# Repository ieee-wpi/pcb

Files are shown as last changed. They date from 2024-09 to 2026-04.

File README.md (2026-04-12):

# Essentials of PCB Design

[][cc-by-sa]

Project-oriented PCB design course taught at WPI. The course is a evening lecture series where students learn to layout and route an embedded system. Students then receive their boards and assemble them. The class was created by [Daniel Gorbunov](https://github.com/dgorbunov) and [Hubert Liu](https://github.com/124274sashimi) in 2024 and has been run every year since through the [IEEE WPI Student Branch](https://ieee.wpi.edu), which helps fund the class. You can reach us at [gr-pcb@wpi.edu](mailto:gr-pcb@wpi.edu) if you have questions.

### Lectures
| #  | Lecture				 |
| -- |--- 				 |
| 01 | PCB Basics 		 |
| 02 | Project Design |
| 03 | Layout + Routing |
| 04 | Working with KiCad |

### Materials
| Folder 	  | Contents		 |
| -- 	  | --- 			 |
| `datasheets` | Datasheets for major parts  |
| `sample_board`  | Sample board design |
| `slides` | PDFs of slides	 	|
| `starter_board` | Starter template design | 
| `code` | Code examples	 |

### Lecture Recordings

> Note: To access the lecture recordings, you must sign in with a WPI account. This is WPI's policy for Echo360 recordings.

| Year  | Term  | Echo360 |
| ----- | ----- | --- |
| 2024 | A-Term | [Link](https://echo360.org/collection/4c2d5caf-a301-4c32-a2dd-bdd8c8c0b9d9/public) | 
| 2025 | A-Term | [Link](https://echo360.org/collection/bc2acf2f-69f2-4496-9638-cb1b12c30087/public) |
| 2026 | C-Term | [Link](https://echo360.org/collection/0ecf9c61-5003-4061-9b4f-ee87c14e6741/public) |

## Getting Started
Not sure where to get started on your design? You'll need to download and install [KiCad](https://www.kicad.org/download/). You'll also need the [Arduino IDE](https://www.arduino.cc/en/software) to program your board.

### Board
To get started on your own board design, navigate to [starter_board](https://github.com/IEEE-WPI/pcb/tree/main/starter_board) and read the instructions in the `README` file.

### Code
To get started uploading code to your board, navigate to [code](https://github.com/IEEE-WPI/pcb/tree/main/code) and read the instructions in the `README` file.

## License
This work is licensed under a
[Creative Commons Attribution-ShareAlike 4.0 International License][cc-by-sa].

[][cc-by-sa]

[cc-by-sa]: http://creativecommons.org/licenses/by-sa/4.0/
[cc-by-sa-image]: https://licensebuttons.net/l/by-sa/4.0/88x31.png
[cc-by-sa-shield]: https://img.shields.io/badge/License-CC%20BY--SA%204.0-lightgrey.svg

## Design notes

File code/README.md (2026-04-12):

## Code Examples
This folder contains several code examples for the Track 1 board.

### Instructions
In order to program your board, you'll have to first flash a bootloader to your board (this will be done in class for you). Then, you can connect a USB cable to your board, compile, and upload one of the `.ino` files in this folder using the Arduino IDE. You can change and reupload the Arduino code at any time after the bootloader is flashed! 

Before you compile and upload code to your board:
1. Install the FastLED library in the Arduino IDE. Go to `Tools -> Manage Libraries`, and search for `FastLED`.
2. Modify any `#define` statements in the code to match any differences in your board. For example, if your board has a different number of LEDs, make sure to update the code to reflect that.
3. In the top left of the IDE, change your board to `Arduino Leonardo` and port to the USB port your board is connected to.
    - On Windows, the port looks like `COMX` where `X` is the port number. You can use Device Manager to find the port the board is connected to.
    - On macOS, the port looks like `/dev/cu.*`. You can run `ls /dev/cu*` in a shell to find the port the board is connected to.
    
You're encouraged to modify and write custom code for your board! You can look at FastLED's examples for inspiration.

### Demo
The `demo` folder contains a program that utilizes the onboard button to cycle through several different animations. You'll need to install the `Bounce2` debouncing library to compile this program.

### Rainbow
The `rainbow` folder contains a program that will iterate back and forth across the LEDs, changing their hue. This is based on FastLED's "cylon" example code.

### Flashlight
The `flashlight` folder contains a program that will turn all the LEDs on your board to white at their full brightness. Be careful, this is very bright and will use a lot of current!

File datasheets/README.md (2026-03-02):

## Datasheets
This folder contains datasheets for the major parts on the Track 1 board. A full list of exact parts used can be found in `digikey_bom.csv`.

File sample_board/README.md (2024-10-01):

## Sample Board
This folder contains the sample board for the Track 1 design. We've ordered these boards to help demonstrate what the Track 1 boards will do. 

**If you're in Track 1, we encourage you not to look at the sample board files, but rather come up with your own layout and routing solutions**. The sample board by no means represents "the best" design for the board.

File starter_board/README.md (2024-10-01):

## Starter Board

This folder contains the Track 1 starter board files. You'll want to open up the `.kicad_pro` file in KiCad. This is the root project file that will allow you to navigate between your board and schematic views.

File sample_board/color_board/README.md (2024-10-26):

### Color Board
This is a version of the sample board with full color silkscreen on both sides. JLCPCB offers this kind of silkscreen technology, but the Gerbers can only be made with their EDA software EasyEDA. The corresponding `.eprj` EasyEDA project file with the colorful silkscreen can only be opened with *EasyEDA Pro*.

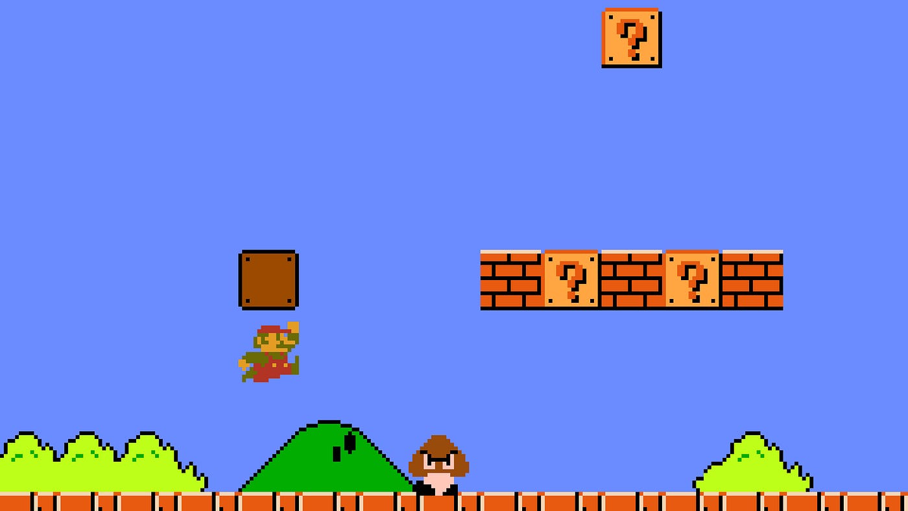
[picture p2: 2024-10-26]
sample_board/color_board/mario.jpg

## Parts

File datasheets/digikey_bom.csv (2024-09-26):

Country of Origin may be different at time of shipment.
Index | Manufacturer Part Number | Manufacturer Name | Description | Availability | Stock Status | Requested Quantity 1 | Pack Quantity 1 | Pack Type 1 | Digi-Key Part Number 1 | Unit Price 1 | Extended Price 1 | Minimum Order Quantity 1 | Requested Part Number | Lead Weeks | Datasheet | US Import Tariff | Note | Part Status | RoHS Status | Moisture Sensitivity Level (MSL) | ECCN | HTSUS | Country of Origin | Environmental Information | Original Part numbers
1 | ATMEGA32U4-AU | Microchip Technology | IC MCU 8BIT 32KB FLASH 44TQFP | 14,657 | In Stock | 1 | 1 | Tray | ATMEGA32U4-AU-ND | 5.29000 | $5.29 | 1 | atmega32u4-au | 4 | http://ww1.microchip.com/downloads/en/DeviceDoc/Atmel-7766-8-bit-AVR-ATmega16U4-32U4_Summary.pdf | - |  | Active | ROHS3 Compliant | 3 (168 Hours) | EAR99 | 8542.31.0015 | Thailand | https://ww1.microchip.com/downloads/aemDocuments/documents/corporate-responsibilty/environmental/product-regulatory-information/Semiconductor_EnvCoC.pdf|https://ww1.microchip.com/downloads/aemDocuments/documents/corporate-responsibilty/environmental/product-regulatory-information/Microchip_REACH_Statement.pdf | atmega32u4-au
2 | 865080142007 | Würth Elektronik | CAP ALUM 100UF 20% 6.3V SMD | 2,805 | In Stock | 1 | 1 | Cut Tape (CT) | 732-8472-1-ND | 0.20000 | $0.20 | 1 | 732-8472-1-ND | 26 | https://www.we-online.com/components/products/datasheet/865080142007.pdf | May apply on shipments to the U.S. |  | Active | ROHS3 Compliant | 1 (Unlimited) | EAR99 | 8532.22.0020 | China | https://mm.digikey.com/Volume0/opasdata/d220001/medias/docus/744/Certificate_of_Compliance_ROHS.pdf | 732-8472-1-ND
3 | CL21B105KPFNNNE | Samsung Electro-Mechanics | CAP CER 1UF 10V X7R 0805 | 763,033 | In Stock | 2 | 2 | Cut Tape (CT) | 1276-1275-1-ND | 0.10000 | $0.20 | 1 | 1276-1275-1-ND | 22 | http://www.samsungsem.com/kr/support/product-search/mlcc/CL21B105KPFNNNE.jsp | - |  | Active | ROHS3 Compliant | 1 (Unlimited) | EAR99 | 8532.24.0020 | Philippines | https://www.samsungsem.com/files/fileDown.do?key=ed1dfdfa-645e-4252-b707-17f9b1502dd1|https://www.samsungsem.com/global/support/certificate/product-stewardship.do | 1276-1275-1-ND
4 | CL21C220JBANFNC | Samsung Electro-Mechanics | CAP CER 22PF 50V C0G/NP0 0805 | 150,218 | In Stock | 2 | 2 | Cut Tape (CT) | 1276-2606-1-ND | 0.10000 | $0.20 | 1 | 1276-2606-1-ND | 22 | http://www.samsungsem.com/kr/support/product-search/mlcc/CL21C220JBANFNC.jsp | - |  | Active | ROHS3 Compliant | 1 (Unlimited) | EAR99 | 8532.24.0020 | China | https://www.samsungsem.com/files/fileDown.do?key=ed1dfdfa-645e-4252-b707-17f9b1502dd1|https://www.samsungsem.com/global/support/certificate/product-stewardship.do | 1276-2606-1-ND
5 | CL21B104KBCNNNC | Samsung Electro-Mechanics | CAP CER 0.1UF 50V X7R 0805 | 1,739,088 | In Stock | 1 | 1 | Cut Tape (CT) | 1276-1003-1-ND | 0.10000 | $0.10 | 1 | 1276-1003-1-ND | 22 | https://mm.digikey.com/Volume0/opasdata/d220001/medias/docus/609/CL21B104KBCNNN_Spec.pdf | - |  | Active | ROHS3 Compliant | 1 (Unlimited) | EAR99 | 8532.24.0020 | Philippines | https://www.samsungsem.com/files/fileDown.do?key=ed1dfdfa-645e-4252-b707-17f9b1502dd1|https://www.samsungsem.com/global/support/certificate/product-stewardship.do | 1276-1003-1-ND
6 | USB3076-30-A | GCT | MICRO B SKT, BOTTOM-SMT, R/A, 30 | 45,985 | In Stock | 1 | 1 | Cut Tape (CT) | 2073-USB3076-30-ACT-ND | 0.70000 | $0.70 | 1 | 2073-USB3076-30-ACT-ND | 9 | https://gct.co/files/specs/usb3076-spec.pdf | May apply on shipments to the U.S. |  | Active | ROHS3 Compliant | Not Applicable | EAR99 | 8536.69.4040 | China | https://gct.co/files/info/gct_certificate_of_compliance.pdf | 2073-USB3076-30-ACT-ND
7 | LNCD1-16M | NDK America, Inc. | CRYSTAL 16.0000MHZ 8PF SMD | 31,951 | In Stock | 1 | 1 | Cut Tape (CT) | 644-LNCD1-16MCT-ND | 0.58000 | $0.58 | 1 | 644-LNCD1-16MCT-ND | 15 | https://mm.digikey.com/Volume0/opasdata/d220001/medias/docus/973/NX5032GA.pdf | - |  | Active | RoHS Compliant | 1 (Unlimited) | EAR99 | 8541.60.0050 | China |  | 644-LNCD1-16MCT-ND
8 | B1701TW--20P000314U1930 | Harvatek Corporation | LED WHITE 0805 SMD | 31,804 | In Stock | 2 | 2 | Cut Tape (CT) | 3147-B1701TW--20P000314U1930CT-ND | 0.10000 | $0.20 | 1 | 3147-B1701TW--20P000314U1930CT-ND | 8 | https://mm.digikey.com/Volume0/opasdata/d220001/medias/docus/3791/B1701TW--20P000314U1930.pdf | - |  | Active | RoHS Compliant | 2A (4 Weeks) | EAR99 | 8541.41.0000 | Taiwan | https://mm.digikey.com/Volume0/opasdata/d220001/medias/docus/6223/Harvatek%20Corp%20REACH%20235%20Jun%202023%20Statement.pdf | 3147-B1701TW--20P000314U1930CT-ND
9 | PH1-20-UA | Adam Tech | CONN HEADER VERT 20POS 2.54MM | 8,135 | In Stock | 1 | 1 | Bag | 2057-PH1-20-UA-ND | 0.36000 | $0.36 | 1 | 2057-PH1-20-UA-ND | 14 | https://app.adam-tech.com/products/download/data_sheet/201605/ph1-xx-ua-data-sheet.pdf | May apply on shipments to the U.S. |  | Active | ROHS3 Compliant | 1 (Unlimited) | EAR99 | 8536.69.4040 | China |  | 2057-PH1-20-UA-ND
10 | PH2-06-UA | Adam Tech | CONN HEADER VERT 6POS 2.54MM | 11,624 | In Stock | 1 | 1 | Bag | 2057-PH2-06-UA-ND | 0.12000 | $0.12 | 1 | 2057-PH2-06-UA-ND | 14 | https://app.adam-tech.com/products/download/data_sheet/202065/ph2-xx-ua-data-sheet.pdf | May apply on shipments to the U.S. |  | Active | ROHS3 Compliant | 1 (Unlimited) | EAR99 | 8536.69.4040 | China |  | 2057-PH2-06-UA-ND
11 | RC0805FR-07100RL | YAGEO | RES 100 OHM 1% 1/8W 0805 | 169,983 | In Stock | 2 | 2 | Cut Tape (CT) | 311-100CRCT-ND | 0.10000 | $0.20 | 1 | 311-100CRCT-ND | 18 | https://www.yageo.com/upload/media/product/products/datasheet/rchip/PYu-RC_Group_51_RoHS_L_12.pdf | May apply on shipments to the U.S. |  | Active | ROHS3 Compliant | 1 (Unlimited) | EAR99 | 8533.21.0030 | Taiwan | https://www.yageo.com/en/Download/Index/certificates#rchip | 311-100CRCT-ND
12 | RC0805FR-0722RL | YAGEO | RES 22 OHM 1% 1/8W 0805 | 499,387 | In Stock | 2 | 2 | Cut Tape (CT) | 311-22.0CRCT-ND | 0.10000 | $0.20 | 1 | 311-22.0CRCT-ND | 18 | https://www.yageo.com/upload/media/product/products/datasheet/rchip/PYu-RC_Group_51_RoHS_L_12.pdf | May apply on shipments to the U.S. |  | Active | ROHS3 Compliant | 1 (Unlimited) | EAR99 | 8533.21.0030 | Taiwan | https://www.yageo.com/en/Download/Index/certificates#rchip | 311-22.0CRCT-ND
13 | RC0805FR-071KL | YAGEO | RES 1K OHM 1% 1/8W 0805 | 1,825,316 | In Stock | 1 | 1 | Cut Tape (CT) | 311-1.00KCRCT-ND | 0.10000 | $0.10 | 1 | 311-1.00KCRCT-ND | 18 | https://www.yageo.com/upload/media/product/products/datasheet/rchip/PYu-RC_Group_51_RoHS_L_12.pdf | May apply on shipments to the U.S. |  | Active | ROHS3 Compliant | 1 (Unlimited) | EAR99 | 8533.21.0030 | Taiwan | https://www.yageo.com/en/Download/Index/certificates#rchip | 311-1.00KCRCT-ND
14 | RC0805FR-07470RL | YAGEO | RES 470 OHM 1% 1/8W 0805 | 415,773 | In Stock | 1 | 1 | Cut Tape (CT) | 311-470CRCT-ND | 0.10000 | $0.10 | 1 | 311-470CRCT-ND | 18 | https://www.yageo.com/upload/media/product/products/datasheet/rchip/PYu-RC_Group_51_RoHS_L_12.pdf | May apply on shipments to the U.S. |  | Active | ROHS3 Compliant | 1 (Unlimited) | EAR99 | 8533.21.0030 | Taiwan | https://www.yageo.com/en/Download/Index/certificates#rchip | 311-470CRCT-ND
15 | 2686 | Adafruit Industries LLC | ADDRESS LED DISC SERIAL RGB 10PK | 185 | In Stock | 1 | 1 | Bulk | 1528-1541-ND | 4.95000 | $4.95 | 1 | 1528-1541-ND | 6 | https://cdn-shop.adafruit.com/product-files/2686/SK6812MINI_REV.01-1-2.pdf | - |  | Active | ROHS3 Compliant | 5A (24 Hours) | EAR99 | 8541.41.0000 | China |  | 1528-1541-ND

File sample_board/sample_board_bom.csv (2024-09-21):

# | Reference | Qty | Value | Footprint | DNP
1 | C1 | 1 | 100uF | Capacitor_SMD:CP_Elec_5x5.3
2 | C2, C6 | 2 | 1uF | Capacitor_SMD:C_0805_2012Metric_Pad1.18x1.45mm_HandSolder
3 | C3, C4 | 2 | 22pF | Capacitor_SMD:C_0805_2012Metric_Pad1.18x1.45mm_HandSolder
4 | C5 | 1 | 0.1uF | Capacitor_SMD:C_0805_2012Metric_Pad1.18x1.45mm_HandSolder
5 | D1 | 1 | TX | LED_SMD:LED_0805_2012Metric_Pad1.15x1.40mm_HandSolder
6 | D2 | 1 | RX | LED_SMD:LED_0805_2012Metric_Pad1.15x1.40mm_HandSolder
7 | D3, D4, D5, D6, D7, D8, D9, D10, D11, D12, D13, D14, D15, D16, D17, D18, D19, D20, D21, D22, D23, D24, D25, D26, D27, D28, D29 | 27 | SK6812MINI | LED_SMD:LED_SK6812MINI_PLCC4_3.5x3.5mm_P1.75mm
8 | J1, J2 | 2 | Conn_01x10 | Connector_PinHeader_2.54mm:PinHeader_1x10_P2.54mm_Vertical
9 | J3 | 1 | ICSP | Connector_PinHeader_2.54mm:PinHeader_2x03_P2.54mm_Vertical
10 | J4 | 1 | USB_B_Micro | Connector_USB:USB_Micro-B_GCT_USB3076-30-A
11 | JP1 | 1 | Jumper_2_Open | Jumper:SolderJumper-2_P1.3mm_Open_TrianglePad1.0x1.5mm
12 | R1, R2 | 2 | 100 | Resistor_SMD:R_0805_2012Metric_Pad1.20x1.40mm_HandSolder
13 | R3, R4 | 2 | 22 | Resistor_SMD:R_0805_2012Metric_Pad1.20x1.40mm_HandSolder
14 | R5 | 1 | 10k | Resistor_SMD:R_0805_2012Metric_Pad1.20x1.40mm_HandSolder
15 | R6 | 1 | 470 | Resistor_SMD:R_0805_2012Metric_Pad1.20x1.40mm_HandSolder
16 | U1 | 1 | ATmega32U4-A | Package_QFP:TQFP-44_10x10mm_P0.8mm
17 | Y1 | 1 | 16MHz | Crystal:Crystal_SMD_5032-2Pin_5.0x3.2mm

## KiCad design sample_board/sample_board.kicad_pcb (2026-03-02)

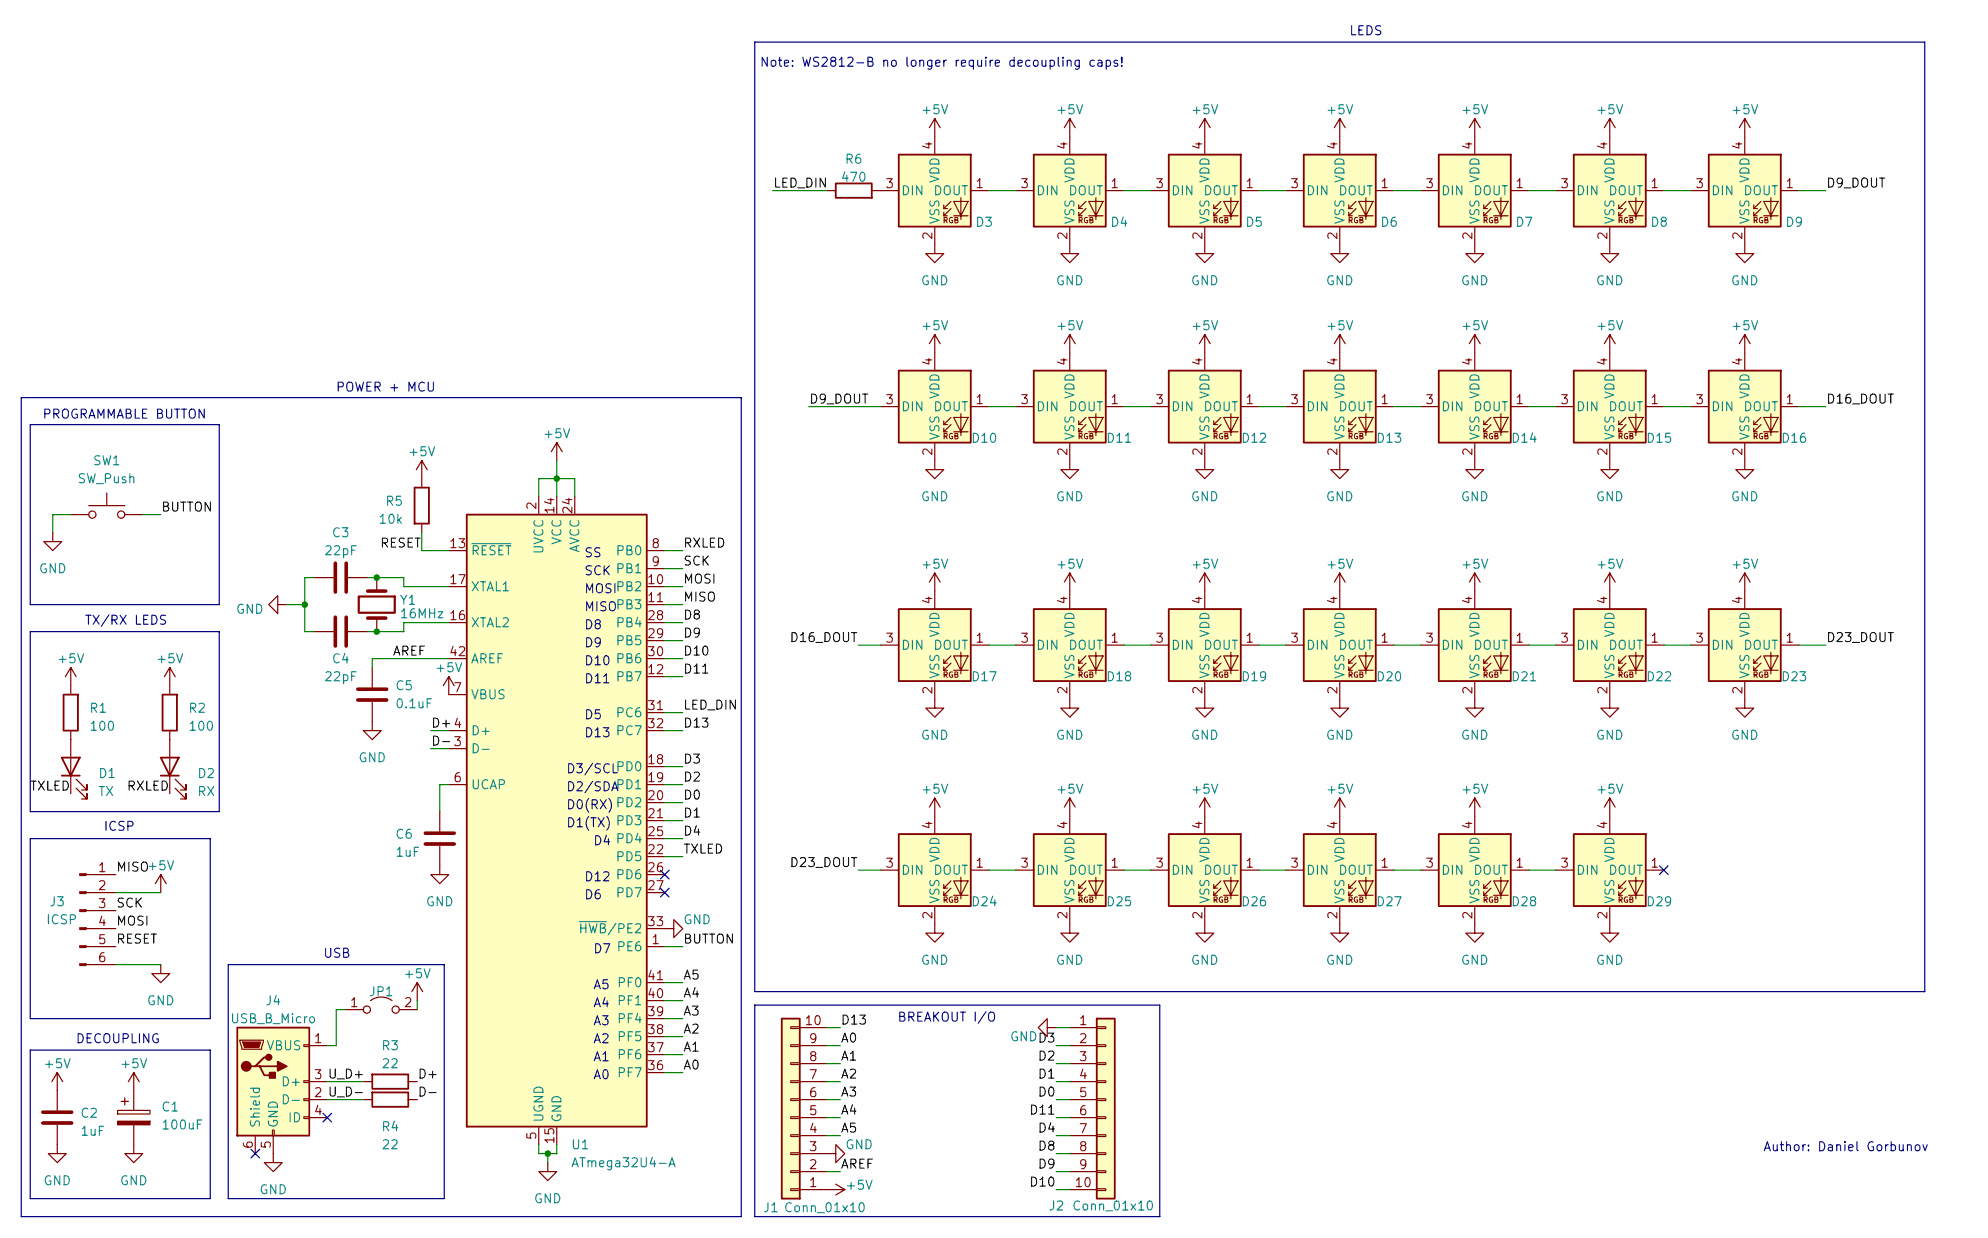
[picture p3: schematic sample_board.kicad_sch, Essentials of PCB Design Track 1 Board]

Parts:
C1: 100uF; CP_Elec_5x5.3
C2, C6: 1uF; C_0805_2012Metric_Pad1.18x1.45mm_HandSolder
C3, C4: 22pF; C_0805_2012Metric_Pad1.18x1.45mm_HandSolder
C5: 0.1uF; C_0805_2012Metric_Pad1.18x1.45mm_HandSolder
D1: TX; LED_0805_2012Metric_Pad1.15x1.40mm_HandSolder
D2: RX; LED_0805_2012Metric_Pad1.15x1.40mm_HandSolder
D3, D4, D5, D6, D7, D8, D9, D10, D11, D12, D13, D14, D15, D16, D17, D18, D19, D20, D21, D22, D23, D24, D25, D26, D27, D28, D29: SK6812MINI; LED_SK6812MINI_PLCC4_3.5x3.5mm_P1.75mm
J1, J2: Conn_01x10; PinHeader_1x10_P2.54mm_Vertical
J3: ICSP; PinHeader_2x03_P2.54mm_Vertical
J4: USB_B_Micro; USB_Micro-B_GCT_USB3076-30-A
JP1: Jumper_2_Open; SolderJumper-2_P1.3mm_Open_TrianglePad1.0x1.5mm
R1, R2: 100; R_0805_2012Metric_Pad1.20x1.40mm_HandSolder
R3, R4: 22; R_0805_2012Metric_Pad1.20x1.40mm_HandSolder
R5: 10k; R_0805_2012Metric_Pad1.20x1.40mm_HandSolder
R6: 470; R_0805_2012Metric_Pad1.20x1.40mm_HandSolder
SW1: SW_Push; SW_SPST_PTS647_Sx38
U1: ATmega32U4-A; TQFP-44_10x10mm_P0.8mm
Y1: 16MHz; Crystal_SMD_5032-2Pin_5.0x3.2mm

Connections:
+5V: C1.1, C2.1, D3.4 (VDD), D4.4 (VDD), D5.4 (VDD), D6.4 (VDD), D7.4 (VDD), D8.4 (VDD), D9.4 (VDD), D10.4 (VDD), D11.4 (VDD), D12.4 (VDD), D13.4 (VDD), D14.4 (VDD), D15.4 (VDD), D16.4 (VDD), D17.4 (VDD), D18.4 (VDD), D19.4 (VDD), D20.4 (VDD), D21.4 (VDD), D22.4 (VDD), D23.4 (VDD), D24.4 (VDD), D25.4 (VDD), D26.4 (VDD), D27.4 (VDD), D28.4 (VDD), D29.4 (VDD), J1.1, J3.2, JP1.2 (B), R1.2, R2.2, R5.1, U1.2 (UVCC), U1.7 (VBUS), U1.14 (VCC), U1.24 (AVCC), U1.34 (VCC), U1.44 (AVCC)
/A0: J1.9, U1.36 (PF7)
/A1: J1.8, U1.37 (PF6)
/A2: J1.7, U1.38 (PF5)
/A3: J1.6, U1.39 (PF4)
/A4: J1.5, U1.40 (PF1)
/A5: J1.4, U1.41 (PF0)
/AREF: C5.1, J1.2, U1.42 (AREF)
/BUTTON: SW1.2, U1.1 (PE6)
/D0: J2.5, U1.20 (PD2)
/D1: J2.4, U1.21 (PD3)
/D2: J2.3, U1.19 (PD1)
/D3: J2.2, U1.18 (PD0)
/D4: J2.7, U1.25 (PD4)
/D8: J2.8, U1.28 (PB4)
/D9: J2.9, U1.29 (PB5)
/D9_DOUT: D9.1 (DOUT), D10.3 (DIN)
/D10: J2.10, U1.30 (PB6)
/D11: J2.6, U1.12 (PB7)
/D13: J1.10, U1.32 (PC7)
/D16_DOUT: D16.1 (DOUT), D17.3 (DIN)
/D23_DOUT: D23.1 (DOUT), D24.3 (DIN)
/D+: R3.1, U1.4 (D+)
/D-: R4.1, U1.3 (D-)
/LED_DIN: R6.1, U1.31 (PC6)
/MISO: J3.1, U1.11 (PB3)
/MOSI: J3.4, U1.10 (PB2)
/RESET: J3.5, R5.2, U1.13 (~RESET)
/RXLED: D2.1 (K), U1.8 (PB0)
/SCK: J3.3, U1.9 (PB1)
/TXLED: D1.1 (K), U1.22 (PD5)
/U_D+: J4.3 (D+), R3.2
/U_D-: J4.2 (D-), R4.2
GND: C1.2, C2.2, C3.2, C4.2, C5.2, C6.2, D3.2 (VSS), D4.2 (VSS), D5.2 (VSS), D6.2 (VSS), D7.2 (VSS), D8.2 (VSS), D9.2 (VSS), D10.2 (VSS), D11.2 (VSS), D12.2 (VSS), D13.2 (VSS), D14.2 (VSS), D15.2 (VSS), D16.2 (VSS), D17.2 (VSS), D18.2 (VSS), D19.2 (VSS), D20.2 (VSS), D21.2 (VSS), D22.2 (VSS), D23.2 (VSS), D24.2 (VSS), D25.2 (VSS), D26.2 (VSS), D27.2 (VSS), D28.2 (VSS), D29.2 (VSS), J1.3, J2.1, J3.6, J4.5 (GND), SW1.1, U1.5 (UGND), U1.15 (GND), U1.23 (GND), U1.33 (~HWB/PE2), U1.35 (GND), U1.43 (GND)
unnamed: D1.2 (A), R1.1
unnamed: D2.2 (A), R2.1
unnamed: D3.3 (DIN), R6.2
unnamed: D3.1 (DOUT), D4.3 (DIN)
unnamed: D4.1 (DOUT), D5.3 (DIN)
unnamed: D5.1 (DOUT), D6.3 (DIN)
unnamed: D6.1 (DOUT), D7.3 (DIN)
unnamed: D7.1 (DOUT), D8.3 (DIN)
unnamed: D8.1 (DOUT), D9.3 (DIN)
unnamed: D10.1 (DOUT), D11.3 (DIN)
unnamed: D11.1 (DOUT), D12.3 (DIN)
unnamed: D12.1 (DOUT), D13.3 (DIN)
unnamed: D13.1 (DOUT), D14.3 (DIN)
unnamed: D14.1 (DOUT), D15.3 (DIN)
unnamed: D15.1 (DOUT), D16.3 (DIN)
unnamed: D17.1 (DOUT), D18.3 (DIN)
unnamed: D18.1 (DOUT), D19.3 (DIN)
unnamed: D19.1 (DOUT), D20.3 (DIN)
unnamed: D20.1 (DOUT), D21.3 (DIN)
unnamed: D21.1 (DOUT), D22.3 (DIN)
unnamed: D22.1 (DOUT), D23.3 (DIN)
unnamed: D24.1 (DOUT), D25.3 (DIN)
unnamed: D25.1 (DOUT), D26.3 (DIN)
unnamed: D26.1 (DOUT), D27.3 (DIN)
unnamed: D27.1 (DOUT), D28.3 (DIN)
unnamed: D28.1 (DOUT), D29.3 (DIN)
unnamed: J4.1 (VBUS), JP1.1 (A)
unnamed: C6.1, U1.6 (UCAP)
unnamed: C3.1, U1.17 (XTAL1), Y1.1
unnamed: C4.1, U1.16 (XTAL2), Y1.2

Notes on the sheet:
MOSI
D2/SDA
LEDS
D11
D3/SCL
USB
DECOUPLING
D1(TX)
D13
Note: WS2812-B no longer require decoupling caps!
Author: Daniel Gorbunov
PROGRAMMABLE BUTTON
MISO
D10
BREAKOUT I/O
POWER + MCU
TX/RX LEDS
ICSP
SCK
D12
D0(RX)

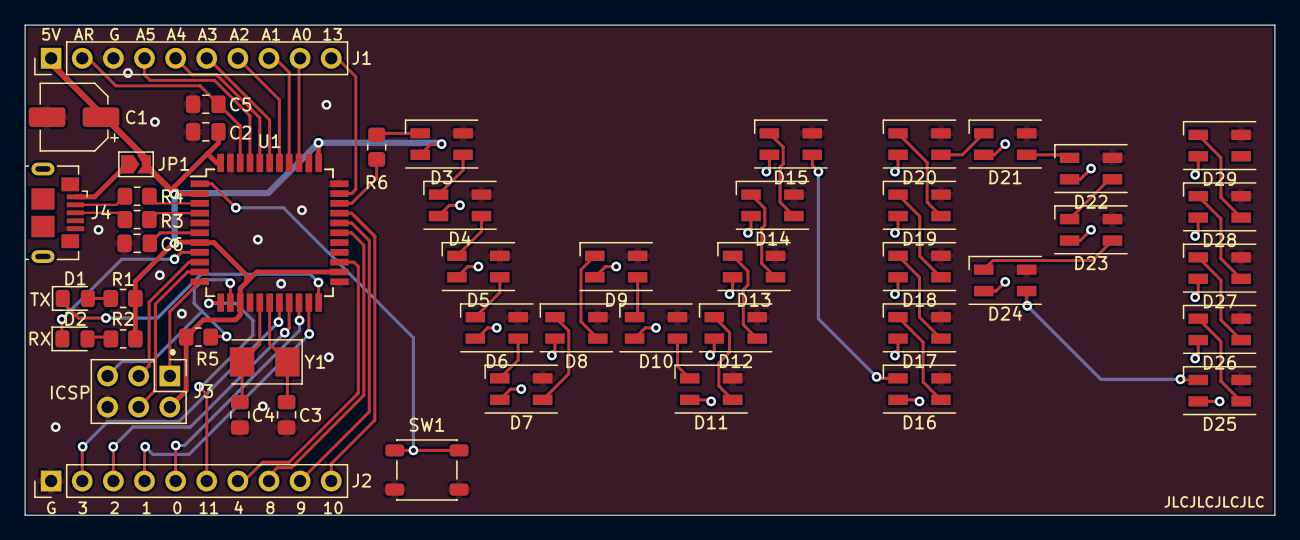
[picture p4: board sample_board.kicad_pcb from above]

Board: 2 copper layers, 102.0 x 40.0 mm, 49 parts (0 on the bottom side), 64 nets.

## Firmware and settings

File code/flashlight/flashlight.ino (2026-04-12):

/*
* Essentials of PCB Design
* Flashlight: Turns on all LEDs to white at full brightness
* This is very bright and will use a lot of current!
*
* Track 1 boards compile for Arduino Leonardo
* Requirements:
* - FastLED library
*/

#include <FastLED.h>

// Board-specific pins
#define NUM_LEDS 27
#define DATA_PIN 5

// Array of LEDs
CRGB leds[NUM_LEDS];

// Setup function - runs once at the start
void setup() { 
  FastLED.addLeds<NEOPIXEL, DATA_PIN>(leds, NUM_LEDS);
}

// Loop function - repeatedly called after setup()
void loop() {
  FastLED.showColor(CRGB(255, 255, 255), 255);
  FastLED.show();
}

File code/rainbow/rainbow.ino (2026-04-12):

/*
* Essentials of PCB Design
* Rainbow: Iterates back and forth across the LEDs, changing their hue.
* 
* Track 1 boards compile for Arduino Leonardo
* Requirements:
* - FastLED library
*/

#include <FastLED.h>

// Board-specific pins
#define NUM_LEDS 27
#define DATA_PIN 5

// Delay after each loop iteration (ms)
#define DELAY 50

// Brightness of all LEDs (0-255)
#define BRIGHTNESS 50

// Array of LEDs
CRGB leds[NUM_LEDS];

// Setup function - runs once at the start
void setup() { 
	FastLED.addLeds<WS2812,DATA_PIN,GRB>(leds,NUM_LEDS);
	FastLED.setBrightness(BRIGHTNESS);
}

// Loop function - repeatedly called after setup()
void loop() { 
	static uint8_t hue = 0;

	// Slide the leds in one direction
	for(int i = 0; i < NUM_LEDS; i++) {
    // Advance hue of current LED and write to LEDs
		leds[i] = CHSV(hue++, 255, 255);
		FastLED.show(); 

    // Fade all LEDs and wait
		fadeall();
		delay(DELAY);
	}

	// Slide the leds in the other direction
	for(int i = NUM_LEDS-1; i >= 0; i--) {
    // Advance hue of current LED and write to LEDs
		leds[i] = CHSV(hue++, 255, 255);
		FastLED.show();

    // Fade all LEDs and wait
		fadeall();
		delay(DELAY);
	}
}

// Scales the brightness of all LEDs
void fadeall() {
  for(int i = 0; i < NUM_LEDS; i++) { 
    leds[i].nscale8(200);
  }
}

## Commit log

2024-09-21 move repo to org
    [ieee_pcb_workshop-B_Cu.gbl, ieee_pcb_workshop-B_Mask.gbs, ieee_pcb_workshop-B_Paste.gbp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]
2024-09-24 cleanup stray gerber files
    [ieee_pcb_workshop-B_Cu.gbl, ieee_pcb_workshop-B_Mask.gbs, ieee_pcb_workshop-B_Paste.gbp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]
2024-09-25 reorg and update readme
    [ieee_pcb_workshop.csv, ieee_pcb_workshop.kicad_pcb, ieee_pcb_workshop.kicad_sch]
2024-09-26 untrack kicad cache files
    [ieee_pcb_workshop.csv, ieee_pcb_workshop.kicad_pcb, ieee_pcb_workshop.kicad_sch]
2024-09-26 add datasheets and new sample board files
    [digikey_bom.csv, sample_board.kicad_pcb, sample_board.kicad_sch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]
2024-09-26 remove cached starter board files
    [ieee_pcb_workshop.csv, starter_board.kicad_pcb, starter_board.kicad_sch]
2024-09-26 update board files for A24
    [sample_board.kicad_pcb, starter_board.kicad_pcb, starter_board.kicad_sch]
2024-09-26 add d24 gerbers and update readme
2024-09-27 add gerbers
2024-09-27 update design slide with fixed image
    [flashlight.ino]
2024-10-01 add sample board readme
2024-10-01 lock components
    [starter_board.kicad_pcb]
2024-10-06 sample board rev2; added button
    [sample_board.kicad_pcb, sample_board.kicad_sch]
2024-10-26 regenerate gerbers
    [sample_board.kicad_pcb]
2024-10-26 restore d24 board
2024-10-26 add colorful silkscreen board
2025-10-02 Add updated term to board
    [starter_board.kicad_pcb]
2026-02-20 Update starter board for KiCad 9.0.7
    [starter_board.kicad_pcb, starter_board.kicad_sch]
2026-03-02 Update sample board for KiCad 9
    [sample_board.kicad_pcb, sample_board.kicad_sch]

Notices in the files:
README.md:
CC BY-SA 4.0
